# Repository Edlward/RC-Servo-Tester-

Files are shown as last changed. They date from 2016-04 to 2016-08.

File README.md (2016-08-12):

# RC-Servo-Tester-
DIY RC Servo Tester (STM32F0 &amp; LABVIEW GUI)

http://www.mylv.net/opensource/opensource_view.aspx?BID=96435

<object width="845" height="510">
<iframe width="1280" height="720" src="https://www.youtube.com/embed/h2mnOkbDfCk" frameborder="0" allowfullscreen></iframe>
</object>

http://youtu.be/h2mnOkbDfCk

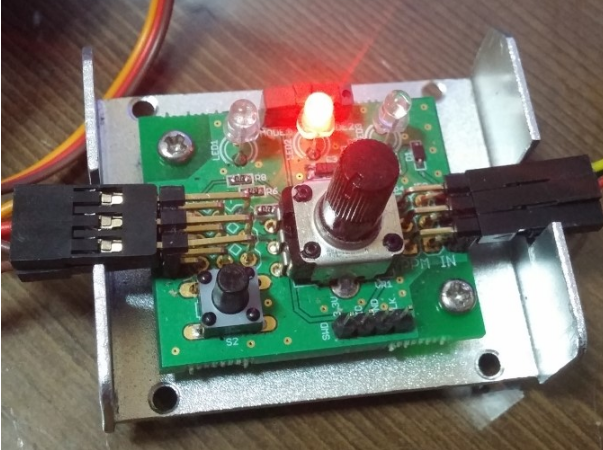
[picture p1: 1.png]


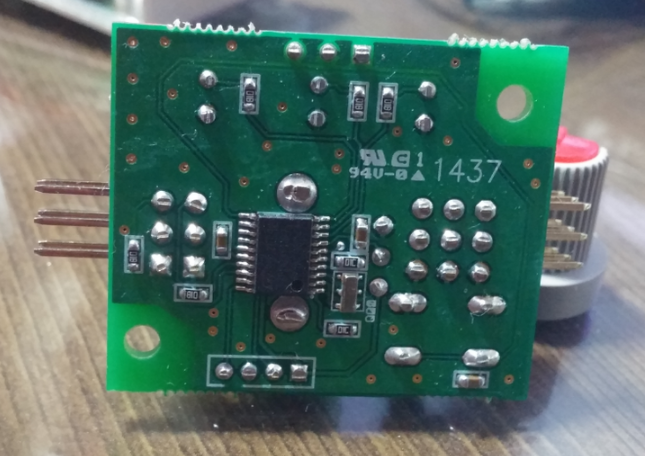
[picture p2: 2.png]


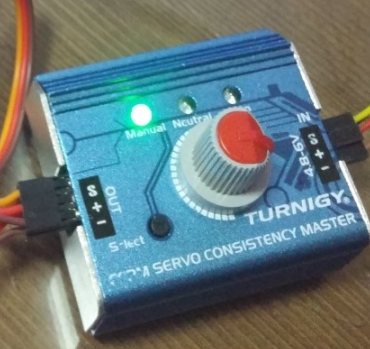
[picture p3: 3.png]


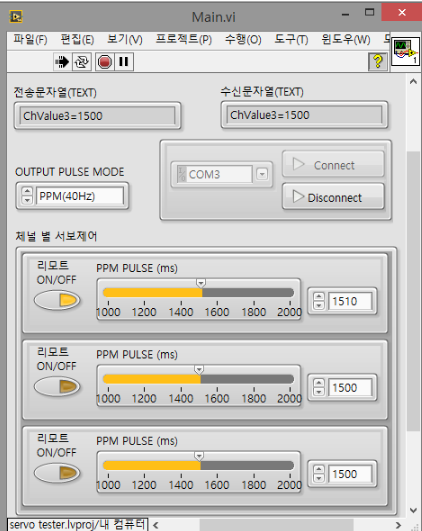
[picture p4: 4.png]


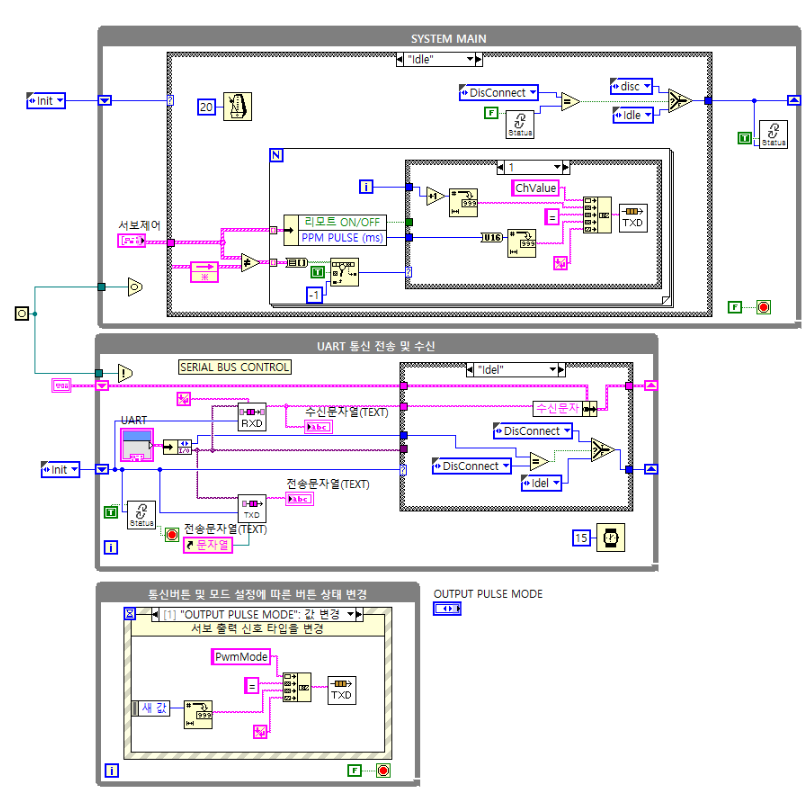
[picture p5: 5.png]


집어넣은 기능은 아래와 같습니다.
 1. DIGITAL SERVO MODE  지원(4ms 주기) : 
 주로 쿼드 콥터용 변속기에서 빠른 응답성이 필요해서 순정 변속기를 DIGITAL SERVO MODE 펌웨어로 펍업해서 쓰거나 전용 DIGITAL SERVO MODE로 빠른 펄스 속도를 지원하는 변속기를 구매해서 쓰고있죠.
  볼륨을 최소로 놓고 PUSH BUTTON을 2초이상 누르면 LED3개가 동시에 4번 깜빡이고 DIGITAL SERVO MODE 로 변경됩니다.
   일반 PPM MODE(20ms 펄스주기)로 변경할때에는 볼륨을 최대로 놓고 PUSH BUTTON을 2초이상 누르면 LED가 좌->우->좌 3번 왔다갔다 점멸 하면서 PPM MODE로 변경됩니다.

 2. 서보 테스터 최대 최소 범위 가변 기능 :
볼륨을 중심에 놓고(중심에 볼륨을 놓으면 메뉴얼 모드에서 3개의 LED가 모두 점등되면 중심입니다.) PUSH BUTTON을 2초이상 길게 누르면 PPPM 출력펄스가 최대 최소 값이 변경됩니다.
표준 상태에서는 1.0ms ~ 2.0ms의 HIGH WIDTH PULSE 출력되며, 넓은범위 상태에서는 0.8ms ~ 2.2ms의 펄스 HIGH WIDTH PULSE가 출력되게 됩니다.
3. 가변 자동모드 :
PUSH 버튼을 잛게 누르면 수동제어->중심고정->자동모드 로 동작 모드로 변경됩니다.
자동모드로 설정될경우 맨 우측 LED가 점등되며, 자동모드 상태에서 볼륨을 돌려주면 자동모드로 움직이는 속도가 가변됩니다. (자동모드는 서보테스터에서 최소 PPM PULSE 에서 최대 PPM PULSE가 까지 오르락 내리락 하면서 신호가 출력됩니다.)
턴니지 서보테스터에는 자동 모드는 한가지 속도로 고정되죠
.
4. 출력되는 PPM PULSE의 포지션을 알려주는 LED기능
 넓은 범위 출력으로 서보테스터를 셋팅해서 사용시 PPM PULSE가 1.0ms 포지보다 낮아지면 맨 좌측 LED의 밝기가 어두어 집니다. 반대로 2.0ms 보다 크면 맨 우측 LED가 어두워 지고 중앙(1.498~1.502ms)에 위치할경우 3개의 모든 LED가 들어오게 됩니다.
LED 밝기와 점등 갯수를 보고 서보테스터에서 출력되는 펄스가 1.0인지 2.0인지 중심인지 알수있도록 하였습니다.

5. 원격제어 기능
USB-UART와 서보테스터의 INPUT 핀을 RXD, TXD와 연결하면 PC의 GUI 프로그램에서 서보테스터를 원격으로 제어 가능합니다. GUI프로그램은 LABVIEW로 만들었으며 첨부된 파일에 만들어진 실행 파일 및 소스가 있습니다.

DIGITAL SERVO MODE 와 STANDARD SERVO(ANALOG SERVO) PPM MODE를 변화하는 동영상 입니다.
아날로그 서보라서 DIGITAL SERVO MODE 를 지원 못해서 변경시 웅웅거리는 잡음이 서보에서 나게 됩니다.
이렇게 오래 쓰면 써보 망가집니다. --;
볼륨을 최대로 놓고 푸쉬버튼을 2초이상 눌주면 표준 PPM MODE이고 볼륨을 최소로 놓고 푸쉬버튼을 2초이상 누르면 DIGITAL SERVO MODE로 변경됩니다.

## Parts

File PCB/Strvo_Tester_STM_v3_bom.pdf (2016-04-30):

No. | Parts | Value | Device | Package | Qty | Description
1 | R1, R3 | 10k | | R1608 | 2 | SMD RESISTOR
2 | R2, R4 | 300 | | R1608 | 2 | SMD RESISTOR
3 | R5 | 300 | | R1608 | 1 | SMD RESISTOR
4 | R9, R10 | 1k | | R1608 | 5 | SMD RESISTOR
5 | R6, R7, R8 | 220 | | R1608 | 5 | SMD RESISTOR
6 | VR1 | 10k | RV09H-20SQ | | 1 | RESISTOR-TRIMMER
7 | C1 | 1uF/16V | | C1608 | 1 | MLCC
8 | C2, C5, C6 | 0.1uF | | C1608 | 3 | NON-POLARIZED CAP
9 | C3 | 2.2uF/6V | | C2012/T | 1 | TANTAL CAP
10 | C4 | 10nF | | C1608 | 1 | MLCC
11 | Q1 | 8MHz | CSTCE16M00V53, MURATA | CSTLA_X | 1 | Ceramic Resonators
12 | D1 | B5819W | B5819W | SOD323 | 1 | SHORTKEY DIODE
13 | IC1 | LK112-33 | LK112-33, ST | SOT23-5L | 1 | 3.3V LDO
14 | S1 | SLIDE SW | IMMS-12V | | 1 | SLIDING SWITCH
15 | S2 | TACT SWITCH | KLT-1105B | | 1 | 9.5mm TACT S/W
16 | JP2 | PIN HEADER 2.54mm | 3*3 RIGHT ANGLE PIN HEADER | | 1 | PIN HEADER
17 | IC2 | STM32F030F4P6 | MCU, CORTEX M0, ST | TSSOP20 | 1 | MCU
18 | LED1, LED2, LED3 | RED,YELLOW,GREEN | φ3mm LED | | 3 | ROUND LED
19 | JP3 | PIN HEADER 2.54mm | 2*3 RIGHT ANGLE PIN HEADER | | 1 | PIN HEADER
20 | JP1 | PIN HEADER 2.0mm | PINHD-1X4M | | 1 | SWD DEBUG
21 | 가변저항 노부 | 노부 | B-01 | | 1 | 가변저항 손잡이

서보테스터 BOM

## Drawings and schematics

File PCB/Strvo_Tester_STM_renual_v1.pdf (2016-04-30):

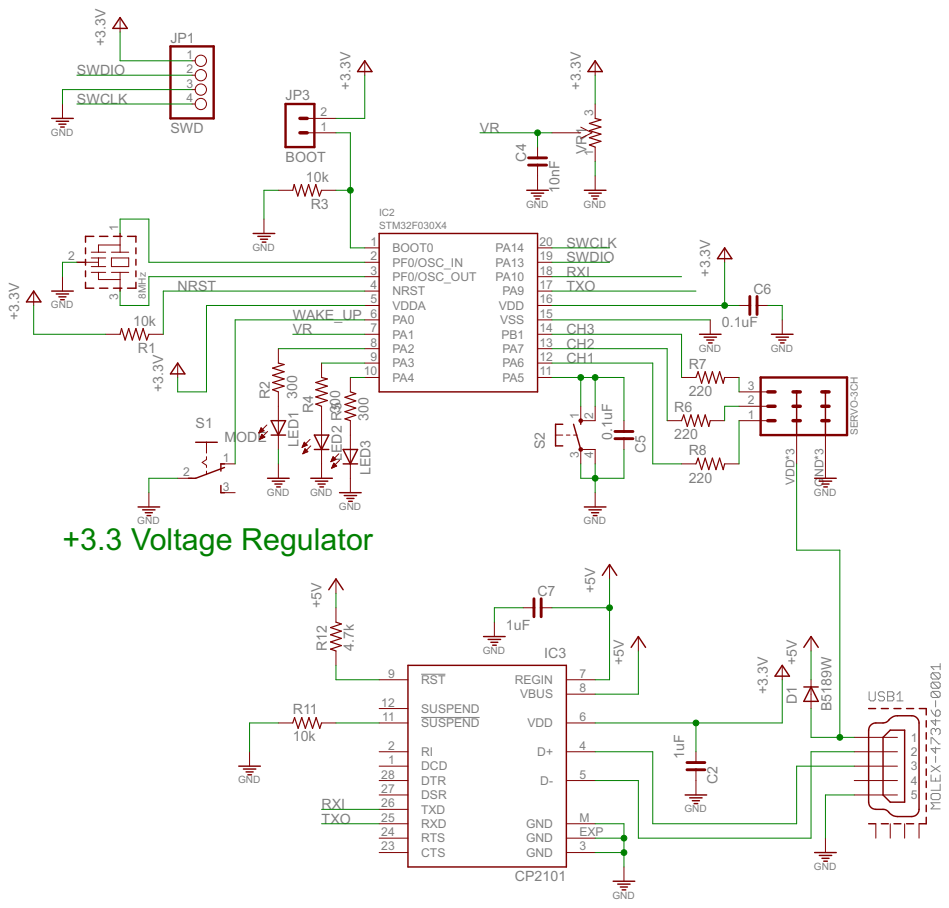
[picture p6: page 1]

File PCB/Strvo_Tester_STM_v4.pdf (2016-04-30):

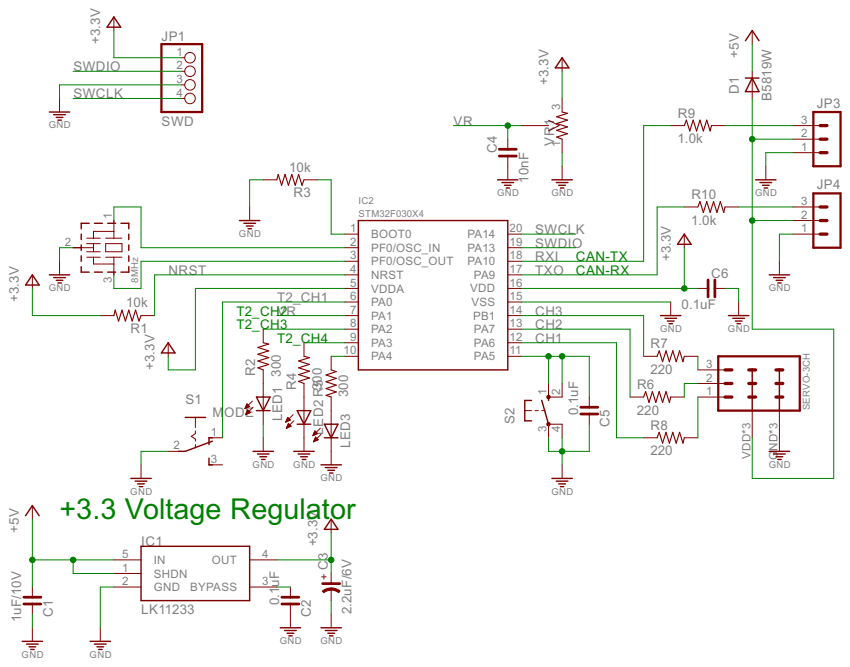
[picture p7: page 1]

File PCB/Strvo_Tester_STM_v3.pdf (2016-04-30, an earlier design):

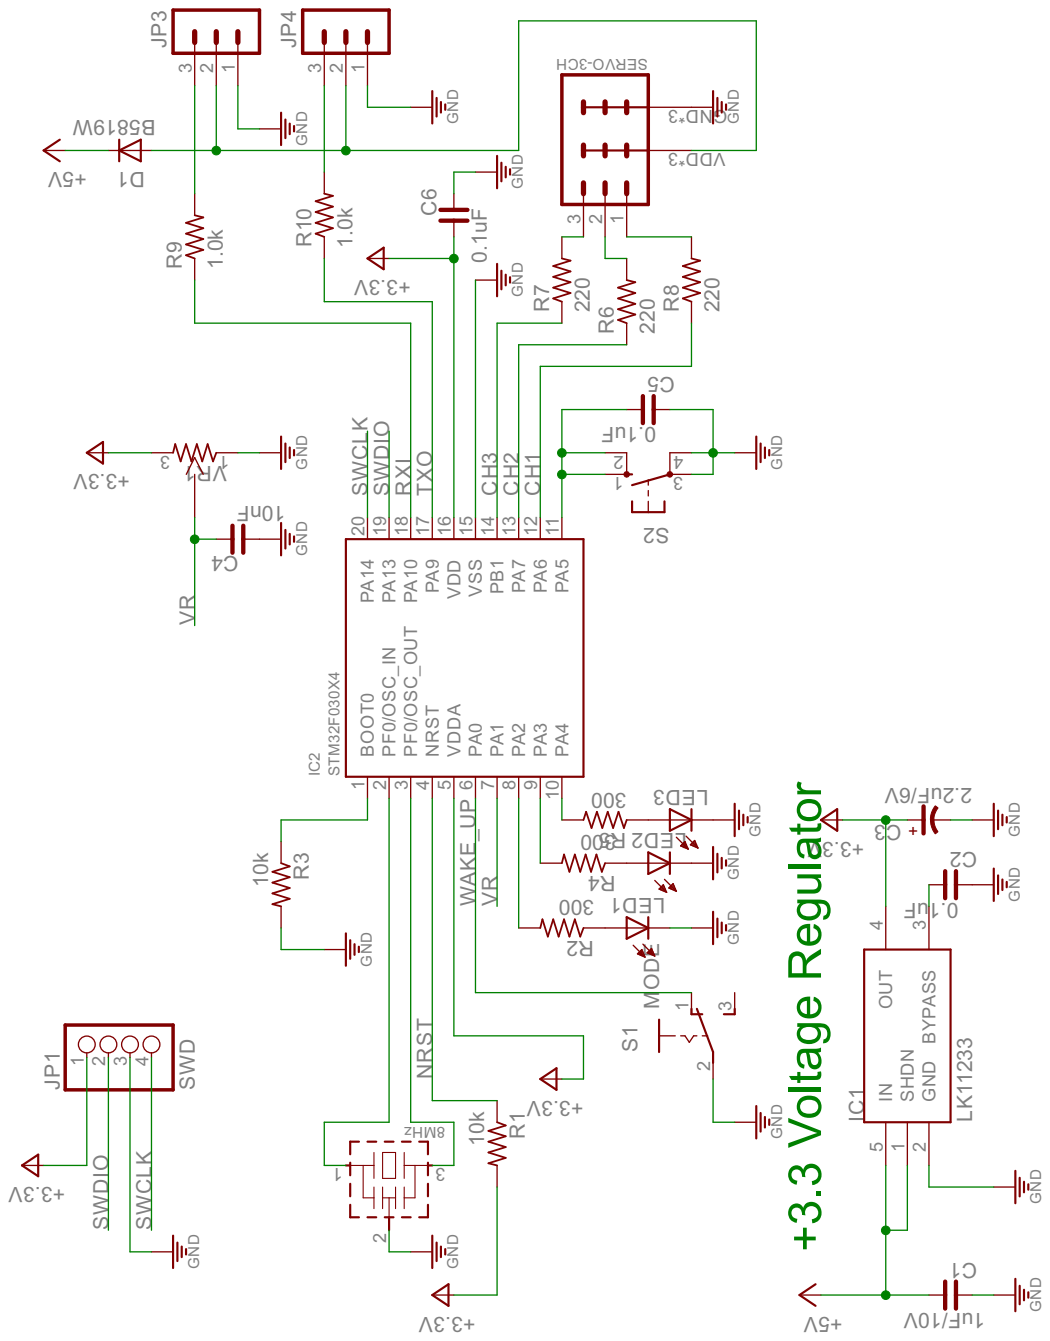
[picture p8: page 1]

GND GND GND GND GND

GND GND

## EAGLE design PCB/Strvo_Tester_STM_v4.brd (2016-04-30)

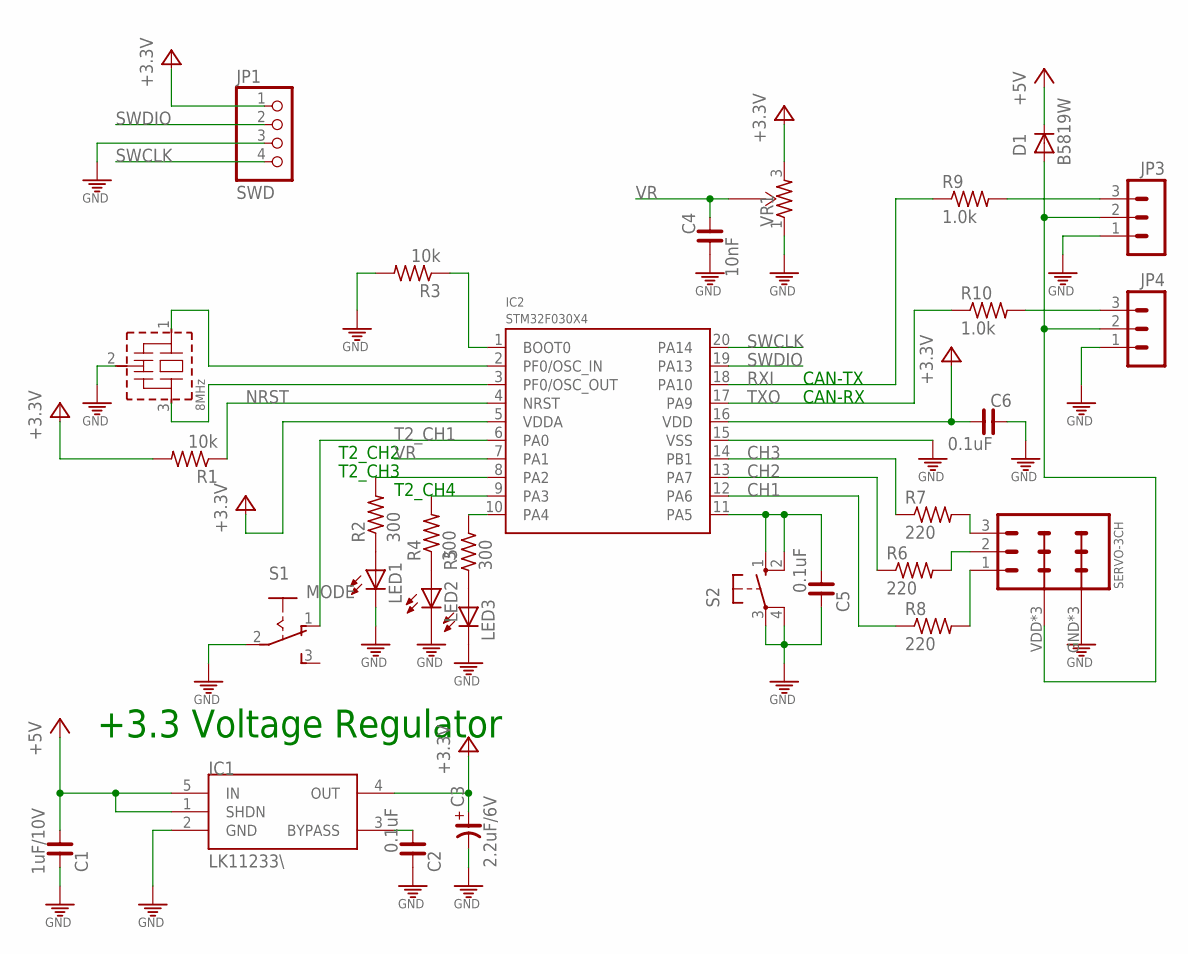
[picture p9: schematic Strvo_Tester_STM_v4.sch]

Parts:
C1: 1uF/10V; C0603
C2, C5, C6: 0.1uF; C0603
C3: 2.2uF/6V; C2012/T
C4: 10nF; C0603
D1: B5819W; SOD323
IC1: LK11233\; SOT23-5L
IC2: STM32F030X4; TSSOP20
JP1: SWD; 1X04M
JP2: SERVO-3CH; SERVO-3CH1
JP3, JP4: MA03-1SMALL; MA03-1-S
LED1, LED2, LED3: LED3MM
Q1: 8MHz; CSTLA_X
R1, R3: 10k; R0603
R2, R4, R5: 300; R0603
R6, R7, R8: 220; R0603
R9, R10: 1.0k; R0603
S1: MODE; 255SB
S2: 10-XX; B3F-10XX
VR1: R-TRIMMER-SMDPTV; PTV09

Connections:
3V3: C3.+, C6.2, IC1.4 (OUT), IC2.5 (VDDA), IC2.16 (VDD), JP1.1, R1.2, VR1.3
+5V: C1.2, D1.C, IC1.1 (SHDN), IC1.5 (IN)
CH1: IC2.12 (PA6), R8.1
CH2: IC2.13 (PA7), R6.1
CH3: IC2.14 (PB1), R7.1
GND: C1.1, C2.1, C3.-, C4.2, C5.1, C6.1, IC1.2 (GND), IC2.15 (VSS), JP1.3, JP2.GND, JP2.GND@1 (GND), JP2.GND@2 (GND), JP3.1, JP4.1, LED1.K (C), LED2.K (C), LED3.K (C), Q1.2 (GND), R3.2, S1.2, S2.3, S2.4 (P1), VR1.1
unnamed: LED1.A, R2.1
unnamed: IC2.2 (PF0/OSC_IN), Q1.1 (IN)
unnamed: IC2.3 (PF0/OSC_OUT), Q1.3 (OUT)
unnamed: JP2.3, R7.2
unnamed: IC2.8 (PA2), R2.2
unnamed: IC2.1 (BOOT0), R3.1
unnamed: C5.2, IC2.11 (PA5), S2.1 (S), S2.2 (S1)
unnamed: C2.2, IC1.3 (BYPASS)
unnamed: JP2.2, R6.2
unnamed: IC2.10 (PA4), R5.2
unnamed: LED2.A, R4.1
unnamed: JP2.1, R8.2
unnamed: IC2.9 (PA3), R4.2
unnamed: JP3.3, R9.2
unnamed: JP4.3, R10.2
unnamed: LED3.A, R5.1
unnamed: D1.A, JP2.VDD (+5V), JP2.VDD@1 (+5V), JP2.VDD@2 (+5V), JP3.2, JP4.2
NRST: IC2.4 (NRST), R1.1
RXI: IC2.18 (PA10), R9.1
SWCLK: IC2.20 (PA14), JP1.4
SWDIO: IC2.19 (PA13), JP1.2
T2_CH1: IC2.6 (PA0), S1.1 (O)
TXO: IC2.17 (PA9), R10.1
VR: C4.1, IC2.7 (PA1), VR1.2

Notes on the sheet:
+3.3 Voltage Regulator
T2_CH2
T2_CH3
T2_CH4
CAN-TX
CAN-RX

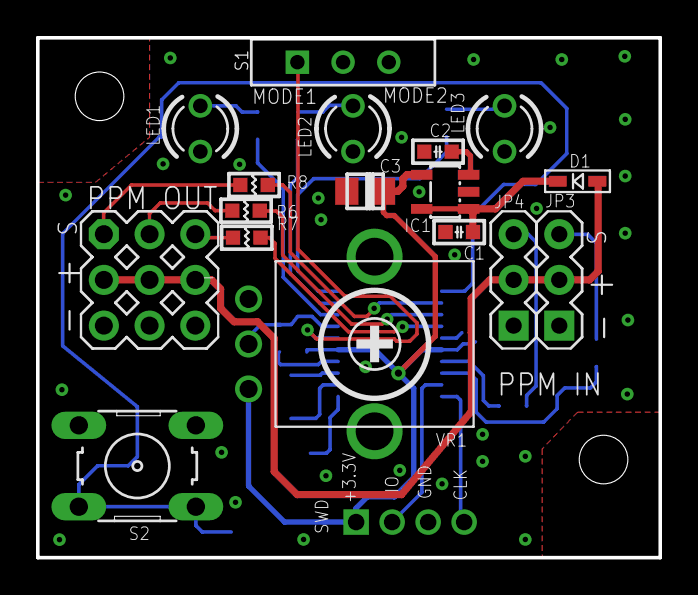
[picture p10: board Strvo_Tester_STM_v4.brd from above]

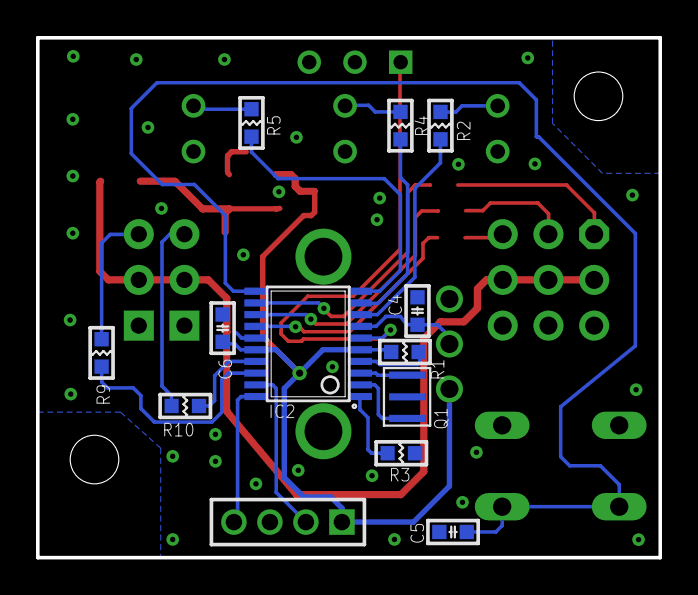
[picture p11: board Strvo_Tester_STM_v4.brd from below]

Board: 2 copper layers, 34.6 x 28.9 mm, 30 parts (13 on the bottom side), 30 nets.

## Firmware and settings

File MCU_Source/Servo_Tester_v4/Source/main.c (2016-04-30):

/* Includes ------------------------------------------------------------------*/
#include "board.h"

/** @addtogroup STM32F0308_Discovery_Peripheral_Examples
  * @{
  */

/** @addtogroup IO_Toggle
  * @{
  */

/* Private typedef -----------------------------------------------------------*/
/* Private define ------------------------------------------------------------*/
//#define BSRR_VAL        0x0300

/* Private macro -------------------------------------------------------------*/
/* Private variables ---------------------------------------------------------*/
//GPIO_InitTypeDef        GPIO_InitStructure;

/* Private function prototypes -----------------------------------------------*/
/* Private functions ---------------------------------------------------------*/

/**
  * @brief  Main program.
  * @param  None
  * @retval None
  */

 void RCC_init(void){
   ErrorStatus HSEStartUpStatus;
   RCC_DeInit(); //RCC system reset(for debug purpose)


   RCC_HSEConfig(RCC_HSE_ON); //Enable HSE
   HSEStartUpStatus = RCC_WaitForHSEStartUp(); //Wait till HSE is ready

 

   if(HSEStartUpStatus == SUCCESS) {
      FLASH_PrefetchBufferCmd(ENABLE); //Enable Prefetch Buffer
      FLASH_SetLatency(FLASH_Latency_1); //Flash 1 wait state
      RCC_HCLKConfig(RCC_SYSCLK_Div1); //HCLK = SYSCLK
	   RCC_PCLKConfig(RCC_HCLK_Div1);
//      RCC_PLLConfig(RCC_PLLSource_HSI_Div2, RCC_PLLMul_6); //PLLCLK = 8MHz * 6 = 48 MHz
      RCC_PLLConfig(RCC_PLLSource_PREDIV1, RCC_PLLMul_6); //PLLCLK = 8MHz * 6 = 48 MHz
      RCC_PLLCmd(ENABLE); //Enable PLL

 

      while (RCC_GetFlagStatus(RCC_FLAG_PLLRDY) == RESET); //Wait till PLL is ready
      RCC_SYSCLKConfig(RCC_SYSCLKSource_PLLCLK); //Select PLL as system clock source
      while (RCC_GetSYSCLKSource() != 0x08); //Wait till PLL is used as system clock source
   }

}	

int main(void) {


	RCC_init();			//Clock Setting
	systemInit();			//GPIO Init
		init_queue(&Uart1RxQueue);
		init_queue(&Uart1TxQueue);
		USART1_Init();
	
		adc_GPIO_Init();
	  ADC_CH_DMA_Config();



	configInit();
	loop_Timer_Init();

	loop_Timer_set(1200);
	
	#ifndef ESC_TEST_MODE
			sys.max_rc = MAX_RC_LIMIT;
			sys.min_rc =MIN_RC_LIMIT;
			pwmOutputConfig.useServos=true;			//fast ppm mode로 동작
			sys.PPM_STDmode=false;
	#else
			sys.max_rc = MAX_RC_LIMIT;
			sys.min_rc =MIN_RC_LIMIT;
			sys.PPM_STDmode =false;
			pwmOutputConfig.useServos=false;			//servo mode로 동작
	#endif

			
		pwmOutputConfig.escPwmRate = FAST_PWM_FREQ;		//Frequency 200Hz
		pwmOutputConfig.servoPwmRate =STANDARD_PWM_FREQ;	//Frequency 50Hz
		pwmWrite(0, (uint16_t)MID_RC);
		pwmWrite(1, (uint16_t)MID_RC);
		pwmWrite(2, (uint16_t)MID_RC);
		pwmOutputInit(&pwmOutputConfig);
	
	EXTI_Config();
	
	
	cfg.ctrl_mode[0] =POTENTIO;
	cfg.ctrl_mode[1] =POTENTIO;
	cfg.ctrl_mode[2] =POTENTIO;





	while (1) {
			uint32_t msNow;
			static uint32_t  actionTime, elapsedTime, oldTime;
			uint8_t i=0;
			msNow = millis();
			elapsedTime = elapsedTime + (msNow - oldTime);
			oldTime = msNow;  

		
				if(actionTime + 5 <= elapsedTime) {		//5ms loop running
						actionTime = elapsedTime;
					
			
					
						switch(sys.runningMode) {
							case MENUAL:
										for(i = 0; i<3;i++) {
												if(	cfg.ctrl_mode[i] == POTENTIO) {
														sys.PPM_CH_vlaue[i] = sys.min_rc + (uint16_t) ((sys.VR_ADC_average*1000)/(4095*1000/((uint32_t)sys.max_rc - sys.min_rc)));
												}
												else {		//uart ppm control 
														sys.PPM_CH_vlaue[i] = cfg.Ch_Value[i];
												}
														pwmWrite(i,sys.PPM_CH_vlaue[i]); 		//VR 위치에 따른 PPM 출력 DUTY 출력

										}

									if(TIM3->CCR1 <= MID_RC+RC_CENTER_RANGE && TIM3->CCR1 >= MID_RC-RC_CENTER_RANGE) {		//중립점시 LED 점멸 
											LED_AUTO_ON;
											LED_MENUAL_ON;
											LED_NETURAL_ON;
	
									}
									else if(TIM3->CCR1 < MIN_RC_STD || TIM3->CCR1 >MAX_RC_STD) {		//표준 범위를 벗어날경우 LED 밝기를 약하게 변경
												static uint8_t k=0;
													switch(k) {
															case 1:
																LED1_ON;
																break;
								
															case 2:
															case 3:
															case 4:
																LED1_OFF;
																break;

															default:
																k=0;
																break;
													}
													k++;

									}
									else {
											LED_MENUAL_ON;
											LED_NETURAL_OFF;
											LED_AUTO_OFF;
									}
									break;

							case NETURAL:
									LED_MENUAL_OFF;
									LED_NETURAL_ON;
									LED_AUTO_OFF;
									pwmWrite(0, (uint16_t)MID_RC);
									pwmWrite(1, (uint16_t)MID_RC);
									pwmWrite(2, (uint16_t)MID_RC);
									break;

							case AUTO:
							//	loop_Timer_set(500+ ADC_Value[VR]/2);
				//					LED_AUTO_ON;
										
									if(TIM3->CCR1 <= MID_RC+2 && TIM3->CCR1 >= MID_RC-2) {		//중립점시 LED 점멸 
											LED_AUTO_ON;
											LED_MENUAL_ON;
											LED_NETURAL_ON;
							//			failureMode(0);
									}
									else {
											LED_AUTO_ON;
											LED_MENUAL_OFF;
											LED_NETURAL_OFF;

										}
									break;

							default :
									break;
						}		//switch 
			
					}
					push_putton_long_push_check(&sys.push_time);		//연속으로 버튼을 누른 시간을 측정
					read_uart_string();
					
					if(sys.VR_ADC_average < 50 && sys.push_time > LONG_PUSH_TIME_MS) {		//최소 상태에서 오래 누를경우
							led_wink_action();
						pwmOutputConfig.useServos=false;		//FAST PWM MODE로 동작	(400Hz = 2.5ms 주기)
						pwm_mode_set();
						sys.runningMode = MENUAL;
					}
					else if(sys.VR_ADC_average > 4045 && sys.push_time > LONG_PUSH_TIME_MS) {		//최대 상태에서 오래 누를경우
						led_street_action();
						pwmOutputConfig.useServos=true;		//STANDARD SERVO MODE로 동작 (40Hz = 25ms 주기)
						pwm_mode_set();
						sys.runningMode = MENUAL;
					}
					else if(sys.VR_ADC_average > 2023 && sys.VR_ADC_average < 2073  && sys.push_time > LONG_PUSH_TIME_MS) {		//중심에 근점하여 길게 누를경우 
						led_boom_action();
						if(sys.PPM_STDmode ==true) {	//wide ppm pulse generation  800 ~ 2200us high width pulse
								sys.max_rc = MAX_RC_LIMIT;
								sys.min_rc =MIN_RC_LIMIT;
								sys.PPM_STDmode =false;
							
						}
						else {		//standart ppm pulse generation  1000 ~ 2000us high width pulse
								sys.max_rc = MAX_RC_STD;
								sys.min_rc =MIN_RC_STD;
								sys.PPM_STDmode =true;
						}
						sys.runningMode = MENUAL;
					}

	}//while(1)
}//main

#ifdef  USE_FULL_ASSERT

/**
  * @brief  Reports the name of the source file and the source line number
  *         where the assert_param error has occurred.
  * @param  file: pointer to the source file name
  * @param  line: assert_param error line source number
  * @retval None
  */
void assert_failed(uint8_t* file, uint32_t line)
{
  /* User can add his own implementation to report the file name and line number,
     ex: printf("Wrong parameters value: file %s on line %d\r\n", file, line) */

  /* Infinite loop */
  while (1)
  {
  }
}
#endif

/**
  * @}
  */

/**
  * @}
  */

/************************ (C) COPYRIGHT STMicroelectronics *****END OF FILE****/

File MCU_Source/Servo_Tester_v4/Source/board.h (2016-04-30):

#pragma once

#include "stm32f0xx.h"

#include <stdbool.h>
#include <stdio.h>
#include <stdlib.h>
//#include <stdint.h>
//#include <math.h>
//#include <ctype.h>
#include <string.h>


//ESC 테스트를 디펄트 동작  모드로 설정시 활성화 , 비활성화시 표준 서보모드(25ms priod로 800~2200us High puls범위로 동작됨.
//#define ESC_TEST_MODE		//FAST PWM & 800~2200 us PWM mode

#define STANDARD_PWM_FREQ		50		//20ms 주기
#define FAST_PWM_FREQ		400				//2.5ms주기

#define MIN_RC_STD		1000
#define MAX_RC_STD	2000

#define MIN_RC_LIMIT		800		//일반적으로 800~2200us 영역을 사용
#define MAX_RC_LIMIT		2200


#define MID_RC 1500
#define PULSE_1p5MS (MID_RC *2)


#define CPPM_SYNC	2700
#define RC_DEADBAND 200
#define RC_TIMEOUT 100000
#define RC_CENTER_RANGE 3	// +2 us

#define LED_ACTION_TIME 300


#define CC_FACTOR 1


//PUSH BUTTON ACTION
#define LONG_PUSH_TIME_MS		2000



#define UART1_BAURD		115200


//------------------ LED DISPLAY --------------------

#define LED1_GPIO   GPIOA
#define LED1_PIN    GPIO_Pin_2

#define LED2_GPIO   GPIOA
#define LED2_PIN    GPIO_Pin_3

#define LED3_GPIO   GPIOA
#define LED3_PIN    GPIO_Pin_4


//---------------  SWITCH INPUT ----------------

#define PUSH_SW_GPIO   GPIOA
#define PUSH_SW_PIN    GPIO_Pin_5
	
#define MODE_SW_GPIO	 GPIOA
#define MODE_SW_PIN			GPIO_Pin_0


//---------------PPM OUTPUT CHANNEL -------------

#define PWM1_GPIO   GPIOA
#define PWM1_PIN    GPIO_Pin_6

#define PWM2_GPIO   GPIOA
#define PWM2_PIN    GPIO_Pin_7

#define PWM3_GPIO   GPIOB
#define PWM3_PIN    GPIO_Pin_1




//JUMPER PAD SETTING 

//#define J1_GPIO  GPIOB
//#define J1_PIN		GPIO_Pin_1

//#define J2_GPIO  GPIOA
//#define J2_PIN		GPIO_Pin_7

//#define J3_GPIO  GPIOA
//#define J3_PIN		GPIO_Pin_3

//#define J4_GPIO  GPIOA
//#define J4_PIN		GPIO_Pin_5

//#define J5_GPIO  GPIOA
//#define J5_PIN		GPIO_Pin_4


//#define TX1_GPIO  GPIOA
//#define TX1_PIN		GPIO_Pin_9
//#define RX1_GPIO  GPIOA
//#define RX1_PIN		GPIO_Pin_10



//RC INPUT PIN SETTING

//#define RC_IN_GPIO		GPIOA
//#define CH1_PIN		GPIO_Pin_9
//#define CH2_PIN		GPIO_Pin_10




#define ir_data_t_END	0xFFFF


#define LED1_TOGGLE              digitalToggle(LED1_GPIO, LED1_PIN)
#define LED1_ON                 digitalHi(LED1_GPIO, LED1_PIN)
#define LED1_OFF                  digitalLo(LED1_GPIO, LED1_PIN)

#define LED2_TOGGLE              digitalToggle(LED2_GPIO, LED2_PIN)
#define LED2_ON                 digitalHi(LED2_GPIO, LED2_PIN)
#define LED2_OFF                  digitalLo(LED2_GPIO, LED2_PIN)

#define LED3_TOGGLE              digitalToggle(LED3_GPIO, LED3_PIN)
#define LED3_ON                 digitalHi(LED3_GPIO, LED3_PIN)
#define LED3_OFF                  digitalLo(LED3_GPIO, LED3_PIN)

#define LED_MENUAL_ON			LED1_ON;
#define LED_MENUAL_OFF			LED1_OFF;
#define LED_NETURAL_ON			LED2_ON;
#define LED_NETURAL_OFF		LED2_OFF;
#define LED_AUTO_ON					LED3_ON;
#define LED_AUTO_OFF					LED3_OFF;



/*
#define IR_LED_TOGGLE              digitalToggle(IR_LED_GPIO, IR_LED_PIN)
#define IR_LED_ON                 digitalHi(IR_LED_GPIO, IR_LED_PIN)
#define IR_LED_OFF                  digitalLo(IR_LED_GPIO, IR_LED_PIN)
*/
//#define SW_TOGGLE              digitalToggle(SW2_GPIO, SW2_PIN)
//#define SW_ON                 digitalHi(SW2_GPIO, SW2_PIN)
//#define SW_OFF                  digitalLo(SW2_GPIO, SW2_PIN)


#define digitalHi(p, i)     { p->BSRR = i; }
#define digitalLo(p, i)     { p->BRR = i; }
#define digitalToggle(p, i) { p->ODR ^= i; }




 //#include "stm32f0xx_conf.h"
#include "drv_system.h"
#include "drv_timer.h"
//#include "rc_input.h"
//#include "ir_protocol.h"
#include "queue.h"
#include "drv_uart.h"
#include "stm32f0xx_it.h"

#include "drv_adc.h"
#include "drv_pwm.h"
#include "drv_keyInput.h"
//#include "drv_flash.h"
#include "config.h"
